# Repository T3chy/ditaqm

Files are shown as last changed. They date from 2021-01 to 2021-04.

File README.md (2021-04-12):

# Do-it-Together Air Quality Measuring!

## Welcome!
Below are the links to all of the documents you need to get your very own distributed air quality sensor mesh set up!

# Paper Abstract
[Check it out!](ABSTRACT.pdf)

## Sensor Setup
- [ESP32](docs/esp32/) (the cool one)

- [Raspberry Pi](docs/raspi/)

## Web server / Database Setup

- [Spin up a dashboard for your data with POST endpoints for data collection!](docs/server.md)

- [Configure and host MySql database to store your data!](docs/db.md)

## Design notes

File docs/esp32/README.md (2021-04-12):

# Embedded, low cost, ESP32 Air Quality Cluster
## What more could you ask for?

## Note

This is currently in development, but you can

-[Read the abstract!](../../ABSTRACT.pdf)

-Check out the [pcb](../../boards/esp32/hardware/pcb/) and [enclosure](../../boards/esp32/hardware) designs!

-Take a look at the [firmware source code!](../../boards/esp32/firmware)

## Welcome!
Below are the steps to set up your very own ESP32-based DITAQM sensor cluster board!

To get a cluster board up and running, you have two options:

[Purchase a Pre-Built board (and support a high school air quality club!)](#pre-built)

[Build it from scratch (don't worry! It's not as hard as it might sound :))](#from-scratch)

## From Scratch!

### Step 1: Ordering the Components and PCBs
I have used [LCSC](https://lcsc.com) for the components and [JLCPCB](https://jlcpcb.com) for the PCBs during development, but there is nothing in the source files that will only work with those distributors. If you want the easiest possible experience, use either Mouser or LCSC for your components, because I have included distributor-specific part numbers for them in the BOM. Ok, let's get ordering!

#### Ordering the components
This will be a guide for ordering the components on LCSC, it is probably similar on any other major components distributor with a BOM tool.

1. Head over to [lcsc](https://lcsc.com) and click on BOM Tool

2. Download the [BOM](../../boards/esp32/hardware/pcb/bom.csv) and upload it to the site

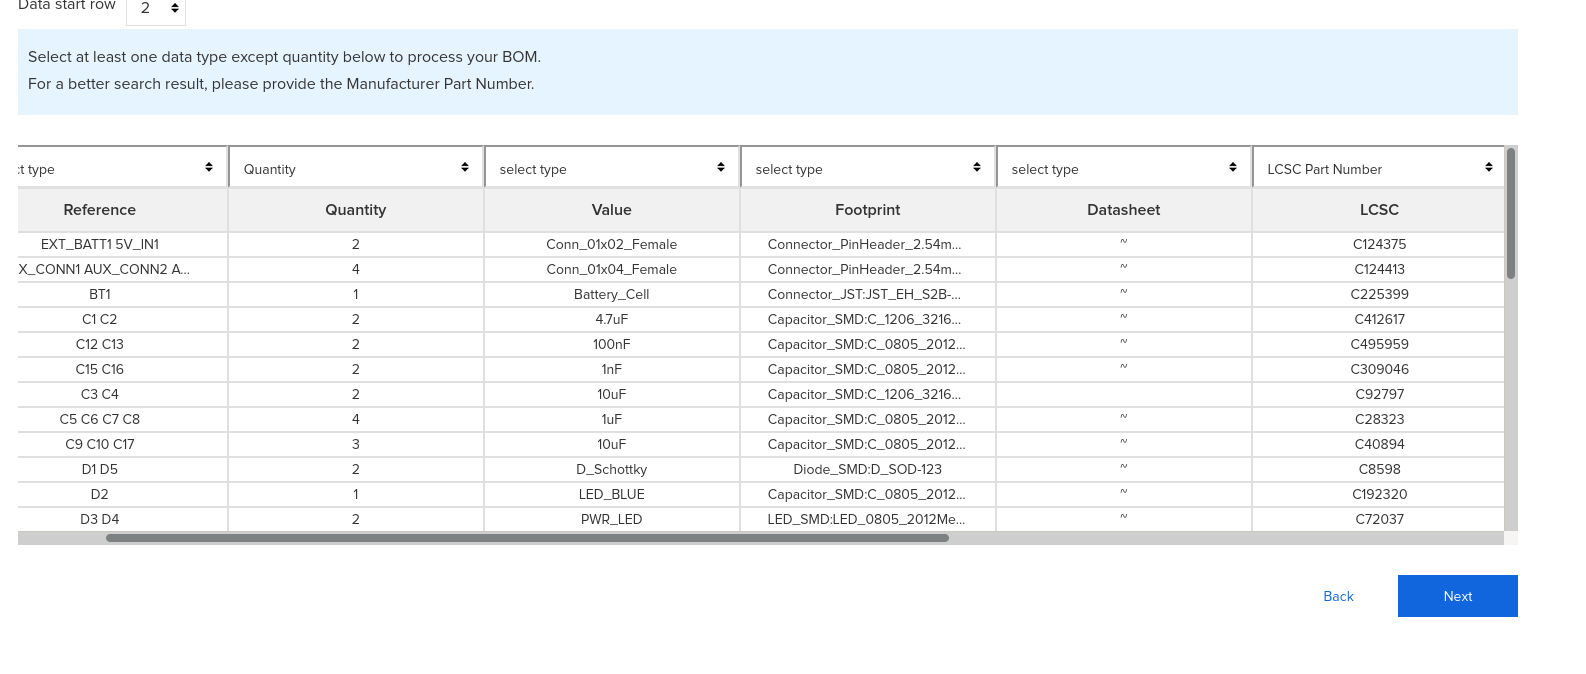
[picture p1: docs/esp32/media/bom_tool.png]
bom tool Finalizing the BOM
3. Once you upload the BOM, you should see a spreadsheet appear. All you need to do is set the "quantity" column to "Quantity" and the "LCSC" column to "LCSC Part Number", as seen in the picture below  

5. Click next, and you will be shown a list of the items required for one unit. Keep in mind that many of the passive components (resistors, capacitors) require a minimum order quanity of between 20 and 100 units, but they cost fractions of cents so don't worry too much about it. Also consider that the BME680 and PMS7003 sensors are included in the LCSC bom, and are by far the most significiant contributors to price. If you laready have these sensors, take them off the list with the trashcan button and that should take your price down quite a bit. Next to the "Add to cart" button there is a multiplier, use that if you are ordering parts for multiple sensor clusters. Keep in mind that if you put, say, 100 qty for a component and multiply that by 4 orders, you will have 400 units in your cart, which is way over the order quantity. Keep that in mind when selecting component qunatities.

7. Once you're ready, you can add the components to cart and check out!

#### Ordering the PCBs
1. Head over to [JLCPCB](https://jlcpcb.com) and click on the big blue "QUOTE NOW" button

2. Download the [PCB Design Files](../../boards/esp32/hardware/pcb/src.zip), click "Add gerber file" and upload the src.zip you just downloaded.

3. Leave all options as default, this will ensure the fastest manfucaturing time and lowest cost

4. Save to cart and checkout!

**Note that JLCPCB will usually take around a week to arrive (with DHL shipping) while LCSC may take up to 2 and a half, depending on which shipping you chose and how long it takes to gather your components in the warehouse**

### Step 2: Assembling
I'll probably make a video on this just open the kicad and follow that or I'll make a key for component designators or smth

**IMPORTANT if you aren't getting any power from the Micro-USB/5V source, check to see if you installed diode D1 backwards! This has happened a few times to me and I only realized that it was the problem when the diode started heating up and I wasn't getting any voltage through the LDO regulator while powered off of the battery.

### Step 3: Flashing the Firmware
If you want, you can use an [esp32-wroom flashing device]() to flash the ESP32 before you solder it in. If you choose to assemble the cluster fully before flashing the firmware, follow the instructions below.

1. Download [esptool]((). This is the standard software package used to flash firmware to Espressif devices, including the ESP32 we are using.
2. Since there is no onboard usb-serial IC on the board, you will need to use an external one. Once you have that device plugged in, wire the external device's RX to your cluster's TX and the device's TX to your cluster's RX. You will also need to connect the ground header on the flashing device to any ground (either marked GND or -, it doesn't matter which one you use) in order to allow voltage to flow. Once you have wired everything up, power the cluster through either a micro usb power supply or a battery, holding the IO0 button before, during, and a few seconds after powering the device. This puts it in 'firmware upload mode' and is the mode we need to be in to flash firmware.

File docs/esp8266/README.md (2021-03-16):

probably just use the esp guide and wire the sensors with jumpers the micropython should be fine

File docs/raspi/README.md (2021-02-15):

# DIYAQI Sensor Deployment Protocol: Raspberry Pi

## Welcome!

Below are the steps to set up your very own Raspberry-Pi based air quality monitoring station

## Table of Contents

**[Components list](#components)**

**[Burning an OS Image](#burning-a-raspberry-pi-os-image)**

**[Pre-Boot Configureatiuon](#headless-config)**

**[First Boot!](#first-boot)**

**[SSHing in](#sshing-in)**

**[Next Steps](#once-youre-in)**

#### Note: If you already have a set up Pi, skip to **[Next Steps](#once-youre-in)**, starting in the home directory

## Components

 Make sure you have all of your components; This includes

	- Raspberry pi Zero W*
	- BME280 Sensor with headers
	- 4 female to female jumper wires
	- a micro USB cable to power your pi
	- a micro SD card (at least 16GB in size)
	- Some way to interface with your microsd card (adapter, port, etc)
	- A computer running Windows, OS X (macOS), or linux**

**Note: you will need to wire up to the GPIO pins on the pi, so gettting a version with presoldered headers is recommended if you don't want to solder them yourself**

*no reason other versions shouldn't work if they have wifi (or are connected to ethernet), but untested

**if you use BSD you probably don't need to be reading this, but welcome! use dd or something lol

## Burning a Raspberry Pi OS Image

Let's get to work! There are two options to burn Raspberry Pi OS onto your pi.

#### Option 1: Raspberry Pi Imager (Recommended)

1. Download the latest version of Raspberry Pi Imager setup from https://www.raspberrypi.org/software/
2. Launch the setup and install it following the instructions shown on screen
3. Plug in your MicroSD card
4. Launch Raspberry Pi Imager
5. Click on `CHOOSE OS` -> `Raspberry Pi OS (other)` -> `Raspberry Pi OS Lite (32-bit)`
	- Note! This tutorial only requires the "Lite" verison, but feel free to download either the "with desktop" or "with desktop and recommended software" versions if you perfer, those will work too!
6. Click on `CHOOSE SD CARD` and select your MicroSD card from the list
7. Click `WRITE` and `YES`, and when it finishes click `CONTINUE` and close the program. Now you should have a bootable version of Raspberry Pi OS! Just a few more things to do before we put that card in the Pi

#### Option 2: Manual (Download Image + BalenaEtcher)

1. Download the latest Raspberry Pi OS (formerly Raspian) image from https://www.raspberrypi.org/software/operating-systems/
	- Note! This tutorial only requires the "Lite" verison, but feel free to download either the "with desktop" or "with desktop and recommended software" versions if you perfer, those will work too!
2. Unzip the image. This can usually be done by right clicking the .zip file and clicking "extract here" or something similar
3. Download and install BalenaEtcher from https://www.balena.io/etcher/ for whatever operating system you are on
4. Plug in your MicroSD card
**Warning: the next steps will wipe all current data on your MicroSD Card**
5. Open BalenaEtcher (you may need to open it with admin privileges)
	- Click "Flash from file" and select the .img you extracted in step 3
	- Click "Select target" and then select your MicroSD card (make sure you aren't accidentally burning the image to a random flash drive that's plugged in!)
	- Click "Flash!" and wait for Etcher to do its thing (flashing and verifying your flash)
6. Once BalenaEtcher finishes, you should have a bootable version of Raspberry Pi OS! Just a few more things to do before we put that card in the Pi

## Headless Config

We will be setting up the pi "headless", which means we won't need to connect anything to it besides power to use it

This requires us to do some manual setup on the pi before we boot it up for the first time, but don't worry! Just follow the instructions carefully and you should be good to go!

Firstly, we need to enable ssh (secure shell) on the pi
	 (secure shell is a method by which a computer can remotley access another computer)

### Enabling secure shell access (ssh)
When you burned your Raspberry pi OS image, there should have been two 'partitions' created on your SD card. They will appear, on most operating systems, as two individual devices. We need to access the "boot" partition, which is the first partition and is also the smaller one. If you cannot find either, the imager may have automatically ejected the MicroSD card. In that case, just remove it and reinsert it.

**Look for files named "start.elf" and "cmdline.txt" to confirm you are in the boot partition**

Once you get into the boot partition, make a file called "ssh" with no extension and save it. An easy way of doing that on Windows is to make a text file but remove the `.txt` extension. Make sure that the system recognizes it as just a "file" and not a text document. The text inside it doesn't matter, so you can put anything you want in there (or nothing, it doesn't matter)

**SSH will now be enabled on first boot!**

### Automatically connecting to WiFi

**Note: skip this section if you are using ethernet (wired internet) for internet connectivity**

To automatically connect to wifi, we need to change a file called "wpa_supplicant.conf"; This file manages your Raspberry Pi automatically connecting to wifi on boot

Luckily, all we need to do is put our wpa supplicant in the boot folder and Rasberry Pi OS will locate it correctly for us! Isn't that nice? Let's do that real quick.

1. Create a file in the same boot folder we just put that 'ssh' file in, call it "wpa_supplicant.conf"
2. In that file put the following text, replacing <SSID> with your wifi network name, and <PASS> with that network's password (keeping the quotes around them)
	- If you live outside of the US, swap "US" for whatever ISO 2 letter code your country has

```
ctrl_interface=DIR=/var/run/wpa_supplicant GROUP=netdev
update_config=1
country=US

network={
 ssid="<SSID>"
 psk="<PASS>"
}
```

**Your device is now ready for its first boot!**

## First boot!

The pi will take a little while to get itself going, go grab a coffee and give around 10 minutes to initalize.

Once you've given your pi 10 minutes to set up, we can access it from our computer!

## SSHing in

For MacOS or linux, you will aready have ssh installed. For windows, you MAY have ssh installed; try the steps below, and if you get an "ssh is not recognized as an internal or external command" kind of thing, follow the instructions for "ssh (PuTTY)" below

### MacOS, Linux, and (Modern) Windows

open your terminal and type in the following command and press enter

```shell
ssh pi@raspberrypi
```

You should be greeted with

```
pi@raspberrypi's password:
```

The default password is "raspberry" (when you type, nothing will show up. This is normal! Just type "raspberry" and press enter)

**Note: you may see something that looks like**
```
The authenticity of host 'raspberrypi (192.168.3.127)' can't be established.
ECDSA key fingerprint is SHA256:/ZBKVpFcCJh4Fl1gzgwIviCVNRWDBXFxL+WTL4TO+Fw.
Are you sure you want to continue connecting (yes/no/[fingerprint])?
```
**before you are prompted for the password, just type "yes" and press enter to continue**

### Legacy Windows (PuTTY)

install [PuTTY](https://www.chiark.greenend.org.uk/~sgtatham/putty/latest.html), a simple ssh client for windows

1. open PuTTY

2. enter "raspberrypi" as the hostname, leave the port at 22 and press "Open"
3. enter "pi" to "Login As:"
4. Enter "raspberry" to "pi@raspberrypi's password:"

## Once you're in
Once you enter the password and press enter, a few lines looking similar to those below will appear (if you got the password right)

```
Linux raspberrypi 4.19.118-v7l+ #1311 SMP Mon Apr 27 14:26:42 BST 2020 armv7l
The programs included with the Debian GNU/Linux system are free software;
the exact distribution terms for each program are described in the
individual files in /usr/share/doc/*/copyright.
Debian GNU/Linux comes with ABSOLUTELY NO WARRANTY, to the extent
permitted by applicable law.
Last login: Fri Jun 26 10:21:38 2020 from 192.168.43.138
pi@raspberrypi:~ $
```

The version number and time will be different, but the important part is that you get that `pi@raspberrypi:~$`. That means you're in (you have a shell, or command line access on/to the pi)!

(*If you want, you can change the default password of "raspberry" by typing "passwd" in the shell prompt, pressing enter, and following the password change prompts*)

We now need to set up the sensor, and get it reporting. You're doing great!

We now need to set up the sensor, configure where we're sending the data, and configure the data-sending script to start every time we turn on our pi. Sounds like a lot, doesn't it? Luckily, most of the process is automated (thanks, scripting!).

All you need to do is run the following command while you're at the `pi@raspberrypi:~ $` prompt

```
wget https://raw.githubusercontent.com/T3chy/diyaqi/main/boards/raspi/setup.sh && sudo chmod +x setup.sh && sudo ./setup.sh
```

**You will be prompted for your password after running this command; simple enter 'raspberry' (without the quotes) or the new password you previosly set and press enter.**

Follow the prompts in the script, and you should be good to go! Congratulations!!

## Troubleshooting

#### "I see \"The package cache file is corrupted\" !! Help!!
**Solution: run**

```
sudo rm -rf /var/lib/apt/lists/*
```

entering your password as needed, and then re run the install script with

```
sudo ./setup.sh
```

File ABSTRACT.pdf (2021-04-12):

# DITAQM- an Educational Framework for a Embedded, Low-Cost, and Open-Source Air Quality Sensor Package

Elam Day-Friedland
Albany High School, Albany, California, USA

April 12, 2021

## Abstract

In this paper, we present a fully integrated framework for distributed air quality sampling with a focus on STEM education and extensions to add more sensors. This is aimed at high-school students with an initial exposure to computer programming. (we expect that teachers / student will do this collaborativley) Within this framework we have included a custom-designed embedded circuit integrating four discrete air quality sensors run by an ESP32 (a WiFi enabled microcontroller). The four natively supported sensors were chosen with consideration for the ability to detect a breadth of pollutants as well as cost and are as follows: the PMS7003 particulate matter sensor, the MiCS6814 MultiGas sensor, the BME280/680 temperature, pressure, humidity, and organic compound (BME680 only) sensor, and the MH-Z19B CO2 NDIR CO2 sensor. The firmware is written in MicroPython, a subset of the Python 3.4 standard optimized for low-spec devices such as microcontrollers, so that it is simple to set up, with no data wires required after initial flashing yet easy to extend. The cluster is contained within a 3D printed enclosure designed to withstand both indoor and harsh outdoor environments. The framework uses a docker-based NodeJS and MySQL stack for handling and coordinating users, sensors, and data. All source files referenced in this paper are available at https://github.com/t3chy/diyaqi. We designed this project to be fully free and open source, with the software and hardware components licensed under the GNU General Public License v3 and CERN Open Hardware License v2 (Strongly Reciprocal) respectively.
© 2021 Elam Day-Friedland

1

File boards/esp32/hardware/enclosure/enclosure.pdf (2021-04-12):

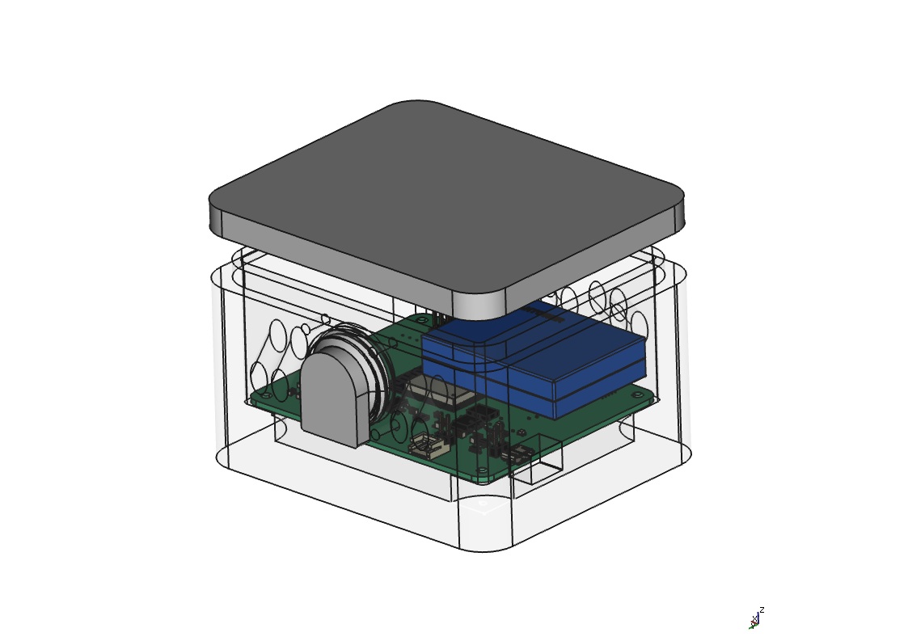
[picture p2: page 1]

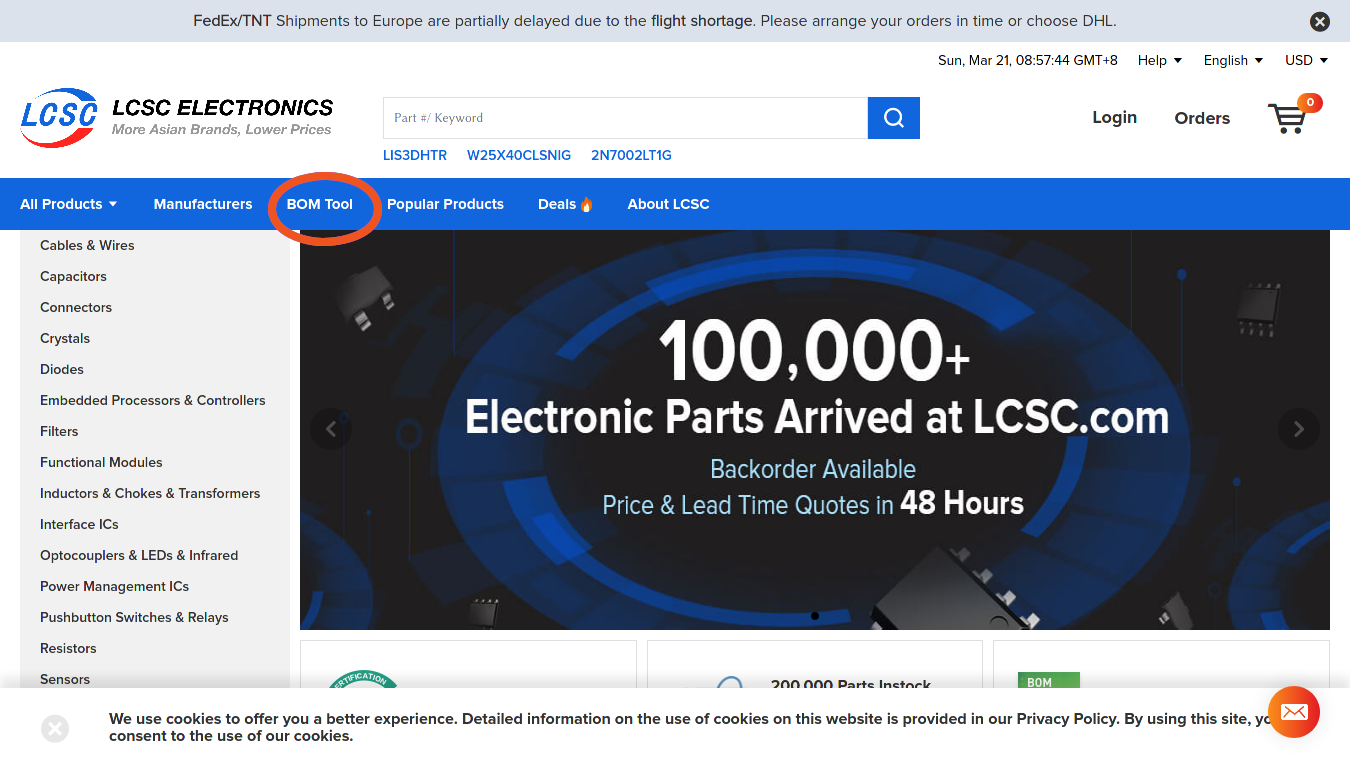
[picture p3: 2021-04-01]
docs/esp32/media/lcsc_home.png

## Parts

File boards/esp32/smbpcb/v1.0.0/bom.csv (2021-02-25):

Reference | Quantity | Value | Footprint | Datasheet | LCSC | mfr_part_num | Mouser
EXT_BATT1 5V_IN1 | 2 | Conn_01x02_Female | Connector_PinHeader_2.54mm:PinHeader_1x02_P2.54mm_Vertical | ~ | C124375 | C124375
AUX_CONN1 AUX_CONN2 AUX_CONN3 AUX_CONN4 | 4 | Conn_01x04_Female | Connector_PinHeader_2.54mm:PinHeader_1x04_P2.54mm_Vertical | ~ | C124413 | C124413
BT1 | 1 | Battery_Cell | Connector_JST:JST_EH_S2B-EH_1x02_P2.50mm_Horizontal | ~ | C225399 | A2501WR-2P
C1 C2 | 2 | 4.7uF | Capacitor_SMD:C_1206_3216Metric | ~ | C412617 |  | 963-UMJ316BC7475KLHT
C12 C13 | 2 | 100nF | Capacitor_SMD:C_0805_2012Metric | ~ | C495959 |  | C0805X104K101TB
C15 C16 | 2 | 1nF | Capacitor_SMD:C_0805_2012Metric | ~ | C309046 |  | TCC0805X7R102K501DTS
C3 C4 | 2 | 10uF | Capacitor_SMD:C_1206_3216Metric | ~ | C412617 |  | 963-UMJ316BC7475KLHT
C5 C6 C7 C8 | 4 | 1uF | Capacitor_SMD:C_0805_2012Metric | ~ | C28323 |  | 187-CL21B105KBFNNNE
C9 C10 C17 | 3 | 10uF | Capacitor_SMD:C_0805_2012Metric | ~ | C40894 |  | 0805X106K250NT
D1 D5 | 2 | D_Schottky | Diode_SMD:D_SOD-123 | ~ | C8598 |  | 833-B5819W-TP
D3 D4 | 2 | PWR_LED | LED_SMD:LED_0805_2012Metric | ~ | C72037 |  | 755-SML-H12U8TT86C
J1 | 1 | USB_B_Micro | Connector_USB:USB_Micro-B_Molex-105017-0001 | ~ | C404969 | MicroXNJ
J2 | 1 | PMS7003 | mics:PMS7003 | https://www.espruino.com/datasheets/PMS7003.pdf | C84815 | PMS7003
L1 | 1 | 4.7uH | Capacitor_SMD:C_0805_2012Metric | ~ | C479902 |  | SCMI201209U4R7KT
Q1 | 1 | SUD08P06-155L | Package_TO_SOT_SMD:TO-252-2 | https://www.vishay.com/docs/62843/sud08p06-155l-ge3.pdf | C558294 |  | 781-SUD08P06-155L-E3
Q2 Q3 | 2 | SS8050_NPN | mics:sot-23-3 |  | C2150 |  | 750-SS8050-G
R1 R15 R25 | 3 | 2k | Capacitor_SMD:C_0805_2012Metric | ~ | C328391 |  | AECR0805F2K00K9
R10 | 1 | 820 | Capacitor_SMD:C_0805_2012Metric | ~ | C352174 |  | AECR0805F820RK9
R11 R12 R13 R14 R16 | 5 | 1k | Capacitor_SMD:C_0805_2012Metric | ~ | C416075 |  | CR-05FL7----1K
R17 R18 | 2 | 4.7k | Capacitor_SMD:C_0805_2012Metric | ~ | C269733 |  | RMC08054.7K5%N
R19 | 1 | 27 | Capacitor_SMD:C_0805_2012Metric | ~ | C104178 |  | RTT0527R0FTP
R2 R3 R4 R5 R22 R23 | 6 | 10k | Capacitor_SMD:C_0805_2012Metric | ~ | C269724 |  | 71-TNPU080510K0AWEN
R20 | 1 | 130 | Capacitor_SMD:C_0805_2012Metric | ~ | C17451 |  | CR0805-FX-1300ELF
R24 R26 R28 | 3 | 470 | Capacitor_SMD:C_0805_2012Metric | ~ | C136570
R27 | 1 | 5.1k | Capacitor_SMD:C_0805_2012Metric | ~ | C328405 |  | 71-CRCW06035K10FKEAC
R6 | 1 | 330k | Capacitor_SMD:C_0805_2012Metric | ~ | C328392 |  | AECR0805F330KK9
SW1 SW2 | 2 | RESET | Button_Switch_SMD:SW_SPST_Omron_B3FS-101xP | ~ | C589246 | ST-1102W-4.3
U1 | 1 | MCP73831-2-OT | Package_TO_SOT_SMD:SOT-23-5 | http://ww1.microchip.com/downloads/en/DeviceDoc/20001984g.pdf | C424093 |  | 579-MCP73831T-2ACIOT
U2 | 1 | SGM6603-5.0YN6G_TR | Package_TO_SOT_SMD:SOT-23-6 | https://www.analog.com/media/en/technical-documentation/data-sheets/4440fb.pdf | C79689 |  | SGM6603-5.0YN6G/TR
U3 | 1 | ESP32-WROOM-32 | RF_Module:ESP32-WROOM-32 | https://www.espressif.com/sites/default/files/documentation/esp32-wroom-32_datasheet_en.pdf | C82899 |  | 356-ESPWROOM3216MB
U4 | 1 | SSD1306 | mics:SSD1306_OLED-0.91-128x32 | https://datasheet.lcsc.com/szlcsc/1809291515_Shenzhen-Allvision-Tech-QG-2832TLBFG02_C91220.pdf | C91220 | QG-2832TLBFG02
U5 | 1 | BME680 | Package_LGA:Bosch_LGA-8_3x3mm_P0.8mm_ClockwisePinNumbering | https://ae-bst.resource.bosch.com/media/_tech/media/datasheets/BST-BME680-DS001.pdf | C125972 | BME680 | 262-BME680
U7 | 1 | AMS1117-3.3 | Package_TO_SOT_SMD:SOT-223-3_TabPin2 | http://www.advanced-monolithic.com/pdf/ds1117.pdf | C369933 | AMS1117-3.3 | 595-REG1117-3.3/2K5

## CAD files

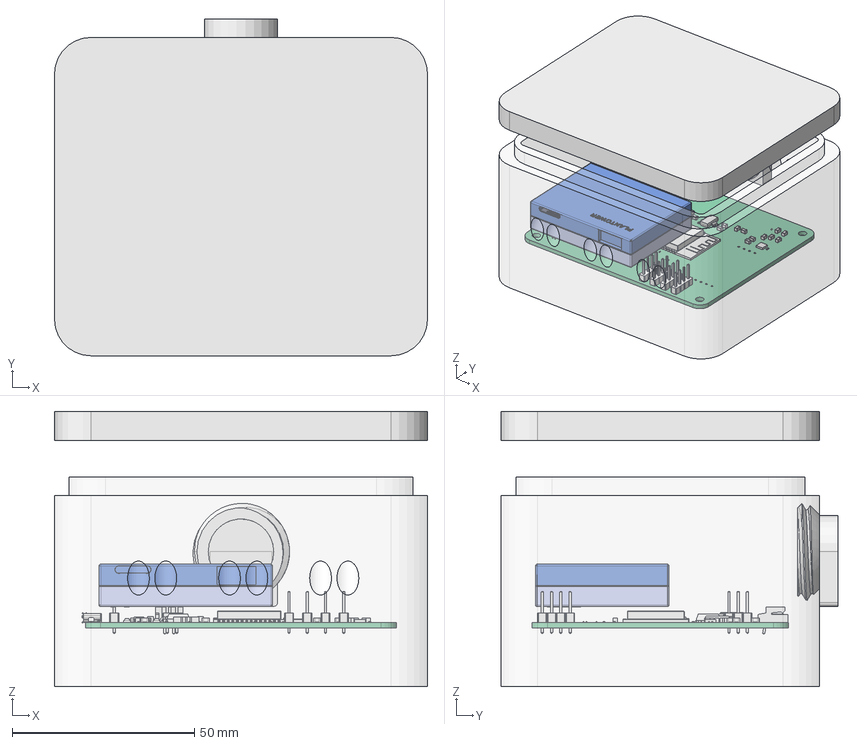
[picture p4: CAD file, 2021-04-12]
boards/esp32/hardware/enclosure/enclosure.FCStd
102.4 x 92.4 x 75.5 mm
Pcb_cdf5
"D5"_D_SOD_123_1408c4fc-6b3f-41e9-9cd8-0f3e23f1e909 x 2
"R28"_C_0201_0603Metric_1e49d41b-6dbe-4e9f-8123-0b88ccebfb2b x 22
"U7"_SOT_223_277a91eb-0315-4cbd-868e-a1e975d6badf
"U1"_SOT_23_5_29c8d3b7-63d8-49c3-b167-1e640a277db6
"EXT_BATT1"_PinHeader_1x02_P254mm_Vertical_2caa2f45-1abb-4877-a58f-1c21ac1dffa2 x 2
"C3"_C_1206_3216Metric_2dba1fc2-255c-43e1-b902-5e91cda70795 x 3
"R8"_C_0805_2012Metric_2f24beb7-e3a1-4d04-bd95-c3c9f92215c0 x 18
"AUX_CONN2"_PinHeader_1x04_P254mm_Vertical_2f8dc1ef-574c-48e6-a60d-e7c7da9fe127 x 4
"Q1"_TO_252_2_30f5009c-511e-4eab-8ab9-cd5aa0241904
"U5"_Bosch_LGA_8_3x3mm_P08mm_ClockwisePinNumbering_4cf723d9-7f93-4c14-b486-45e603f1d024
"U2"_Texas_S_PVSON_N10_62902abe-9812-46b5-a42c-a6af39063f47
"J1"_USB_Micro-B_Molex_47346-0001_7afd3e19-8ad3-4394-a5f0-daa53f96cca8
"BT1"_JST_S2B_EH_a59a4e64-c94d-4edc-84de-77e5b6c3af01
"D3"_LED_0805_2012Metric_aaae8f97-22a9-41f0-8481-7001413f332c x 2
"IC1"_Open CASCADE STEP translator 6.8 1_e548121f-f310-44b3-90db-60773fd45095
"U3"_ESP32-WROOM-32_fbe577f8-ea7d-4210-bfb3-b57f67bc03ec
lid
rain_cover

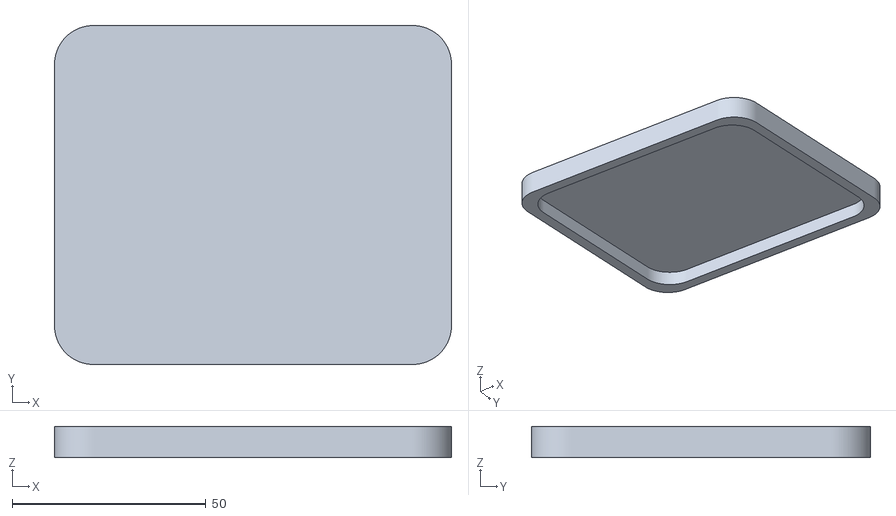
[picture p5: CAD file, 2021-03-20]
boards/esp32/hardware/enclosure/enclosure-lid.stl
102.4 x 87.4 x 8.00

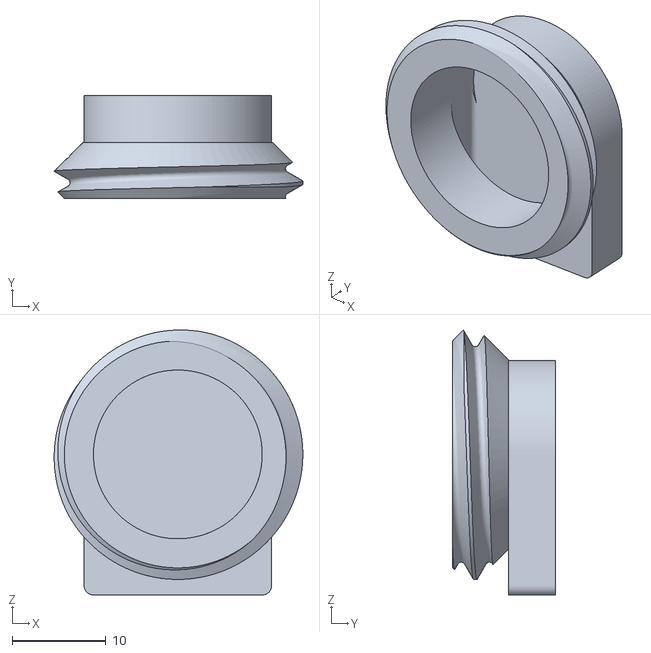
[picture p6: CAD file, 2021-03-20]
boards/esp32/hardware/enclosure/enclosure-rain_cover.stl
26.5 x 11.0 x 28.3

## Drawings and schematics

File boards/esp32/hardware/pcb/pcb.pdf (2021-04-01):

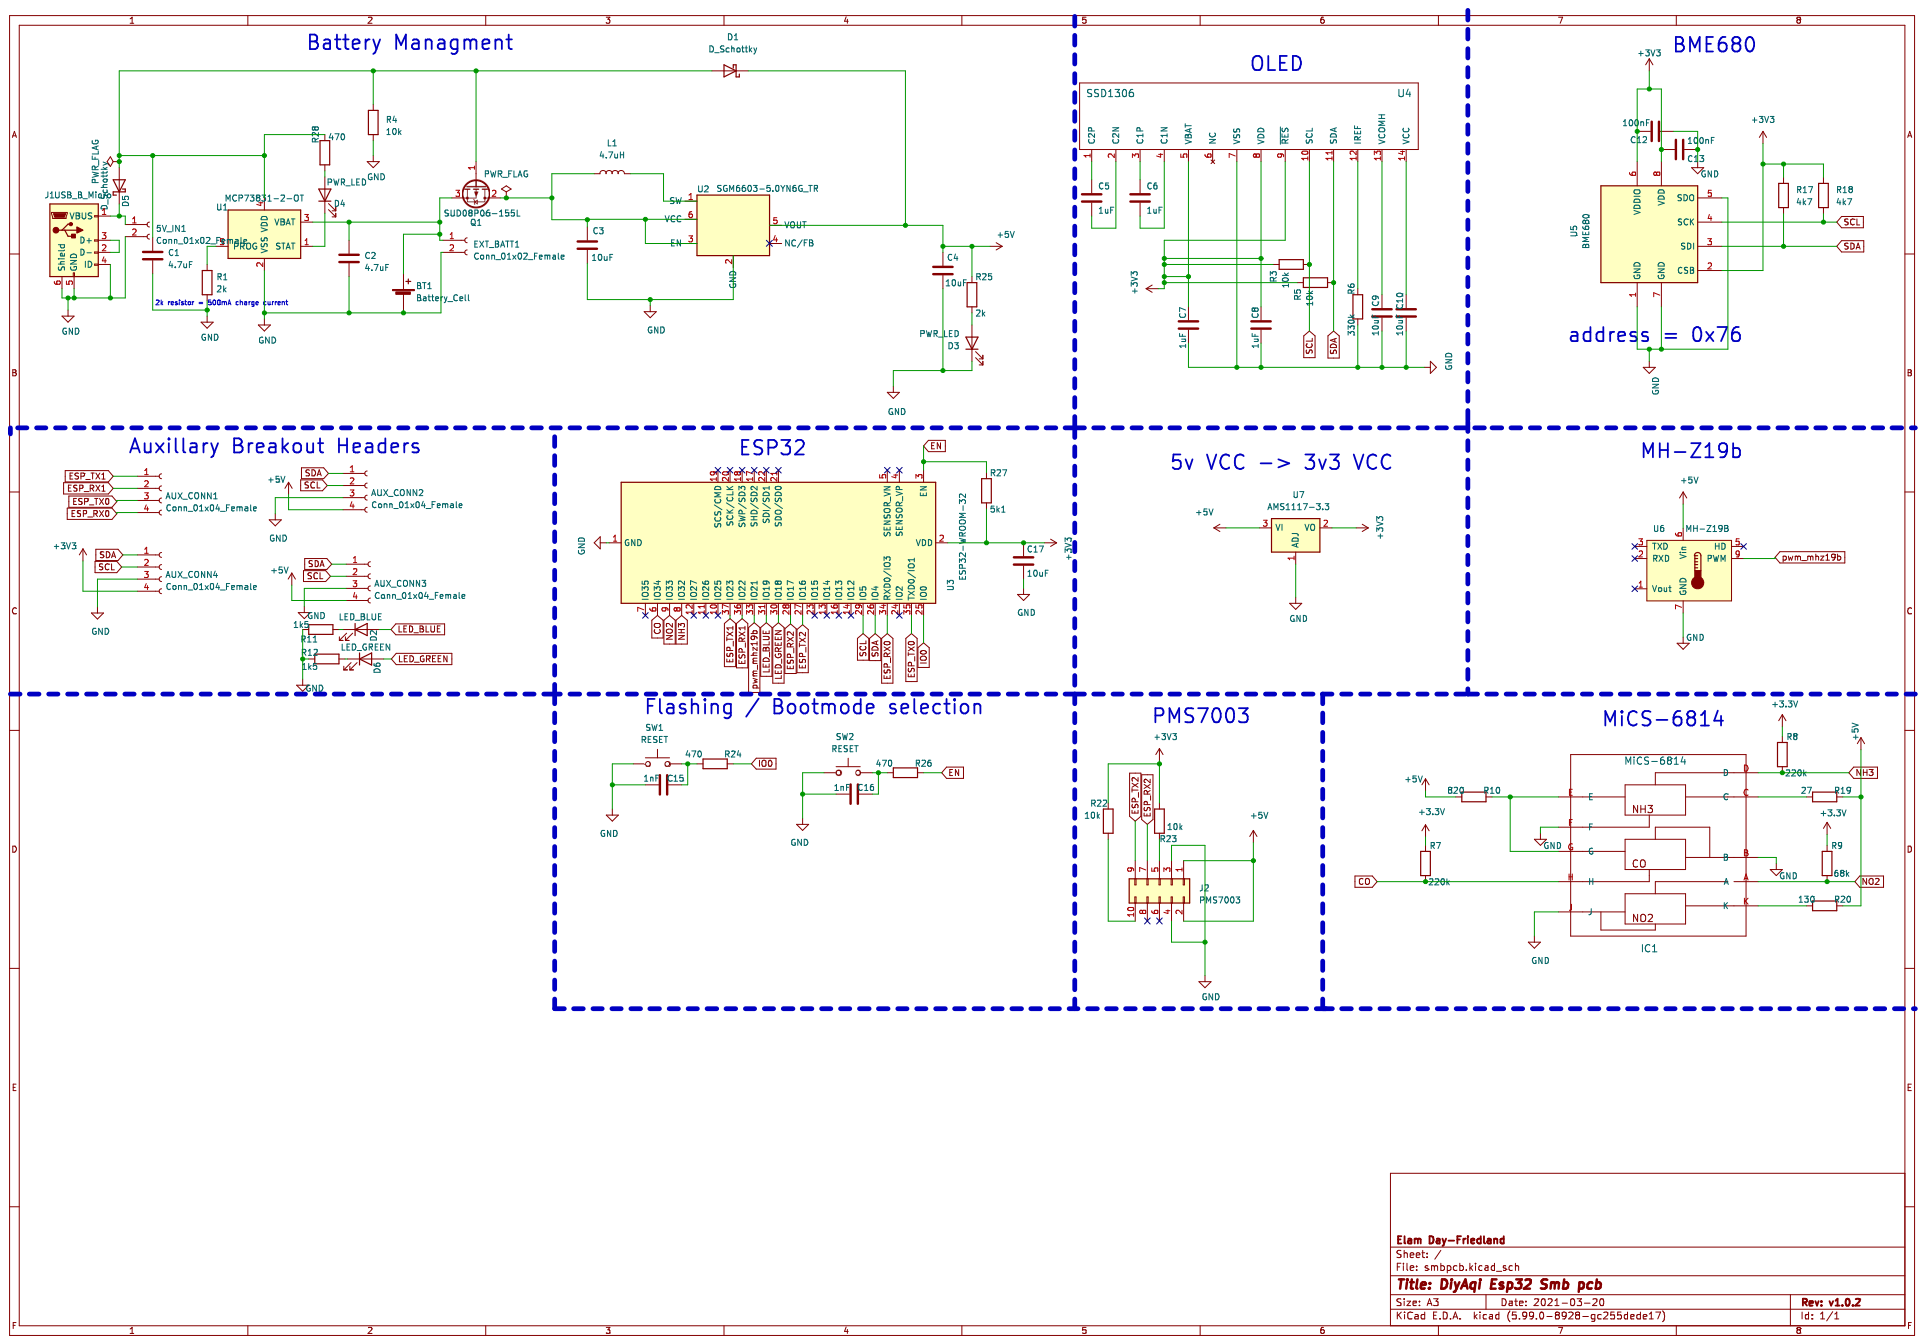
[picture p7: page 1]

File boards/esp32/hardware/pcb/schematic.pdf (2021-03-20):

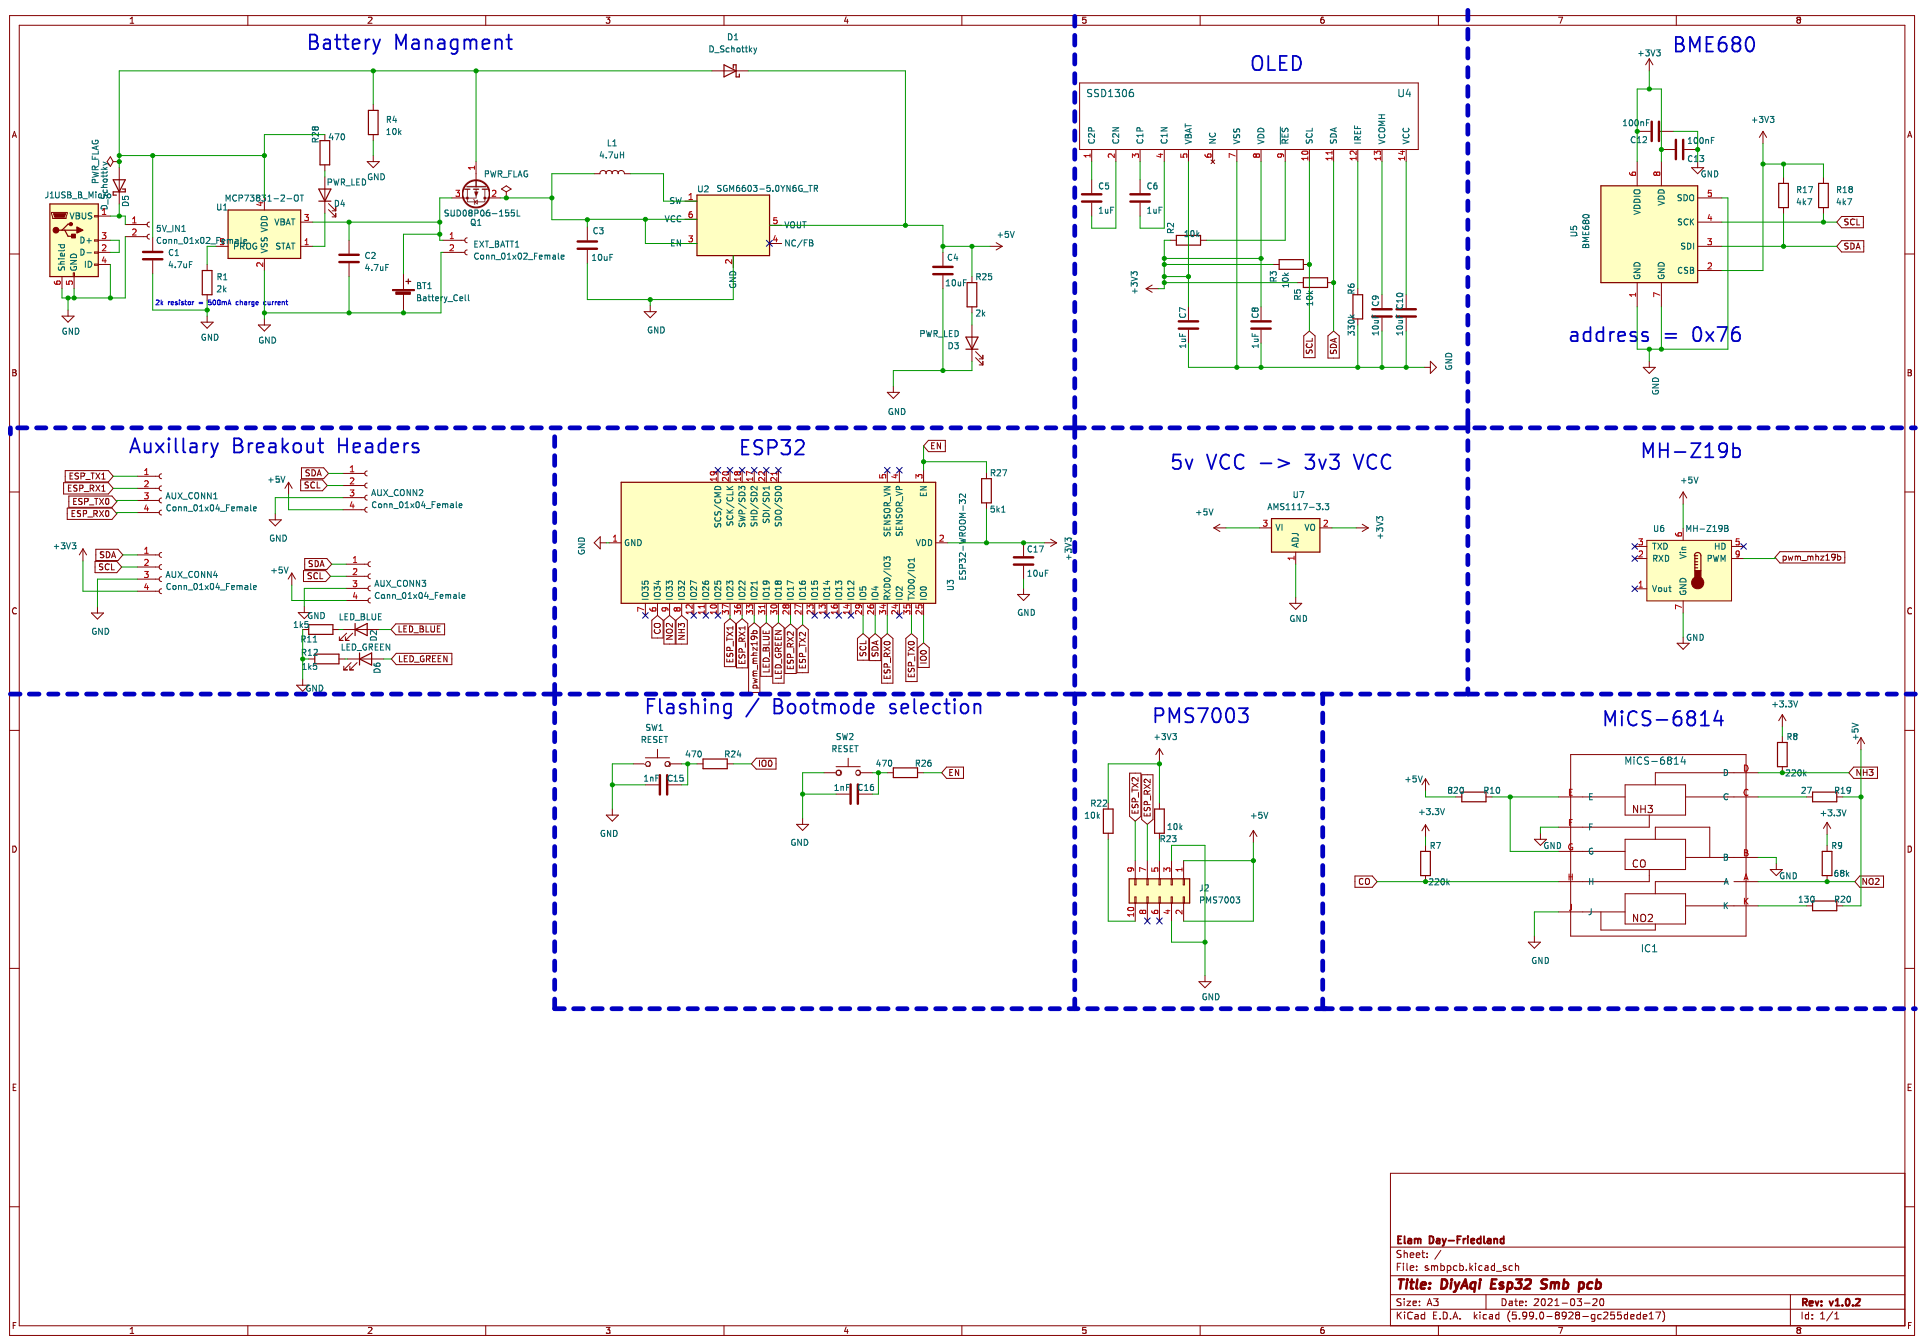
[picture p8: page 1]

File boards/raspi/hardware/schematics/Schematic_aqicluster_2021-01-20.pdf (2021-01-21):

## MH-Z19

CO2

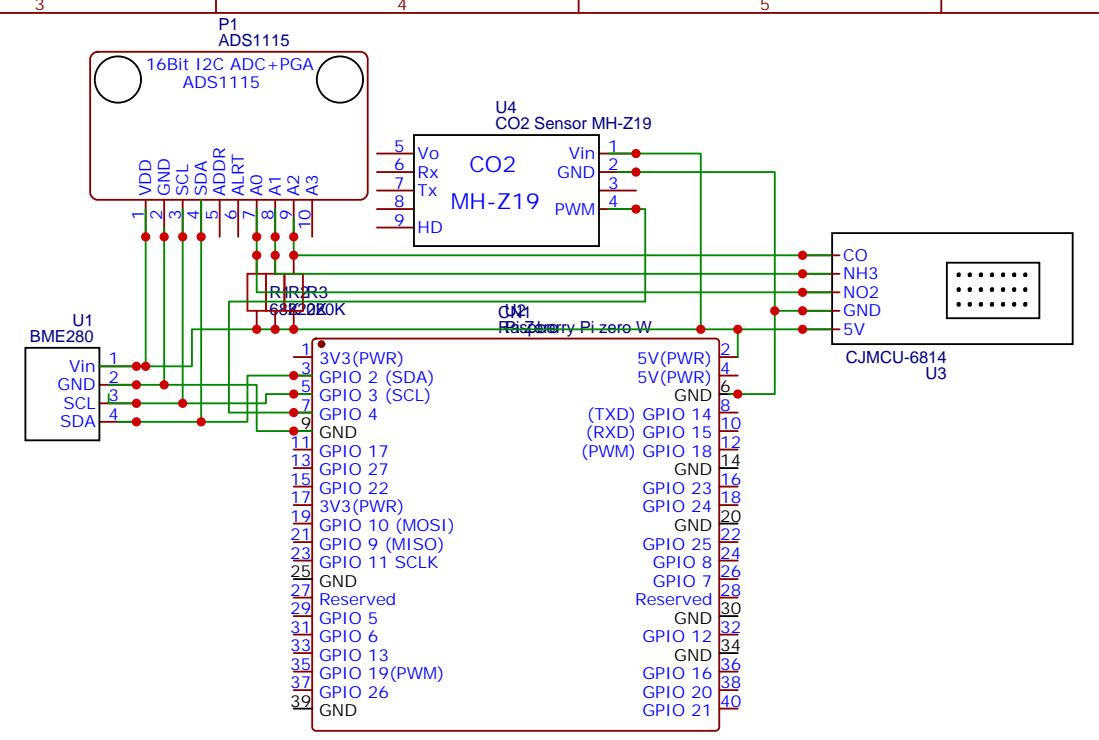
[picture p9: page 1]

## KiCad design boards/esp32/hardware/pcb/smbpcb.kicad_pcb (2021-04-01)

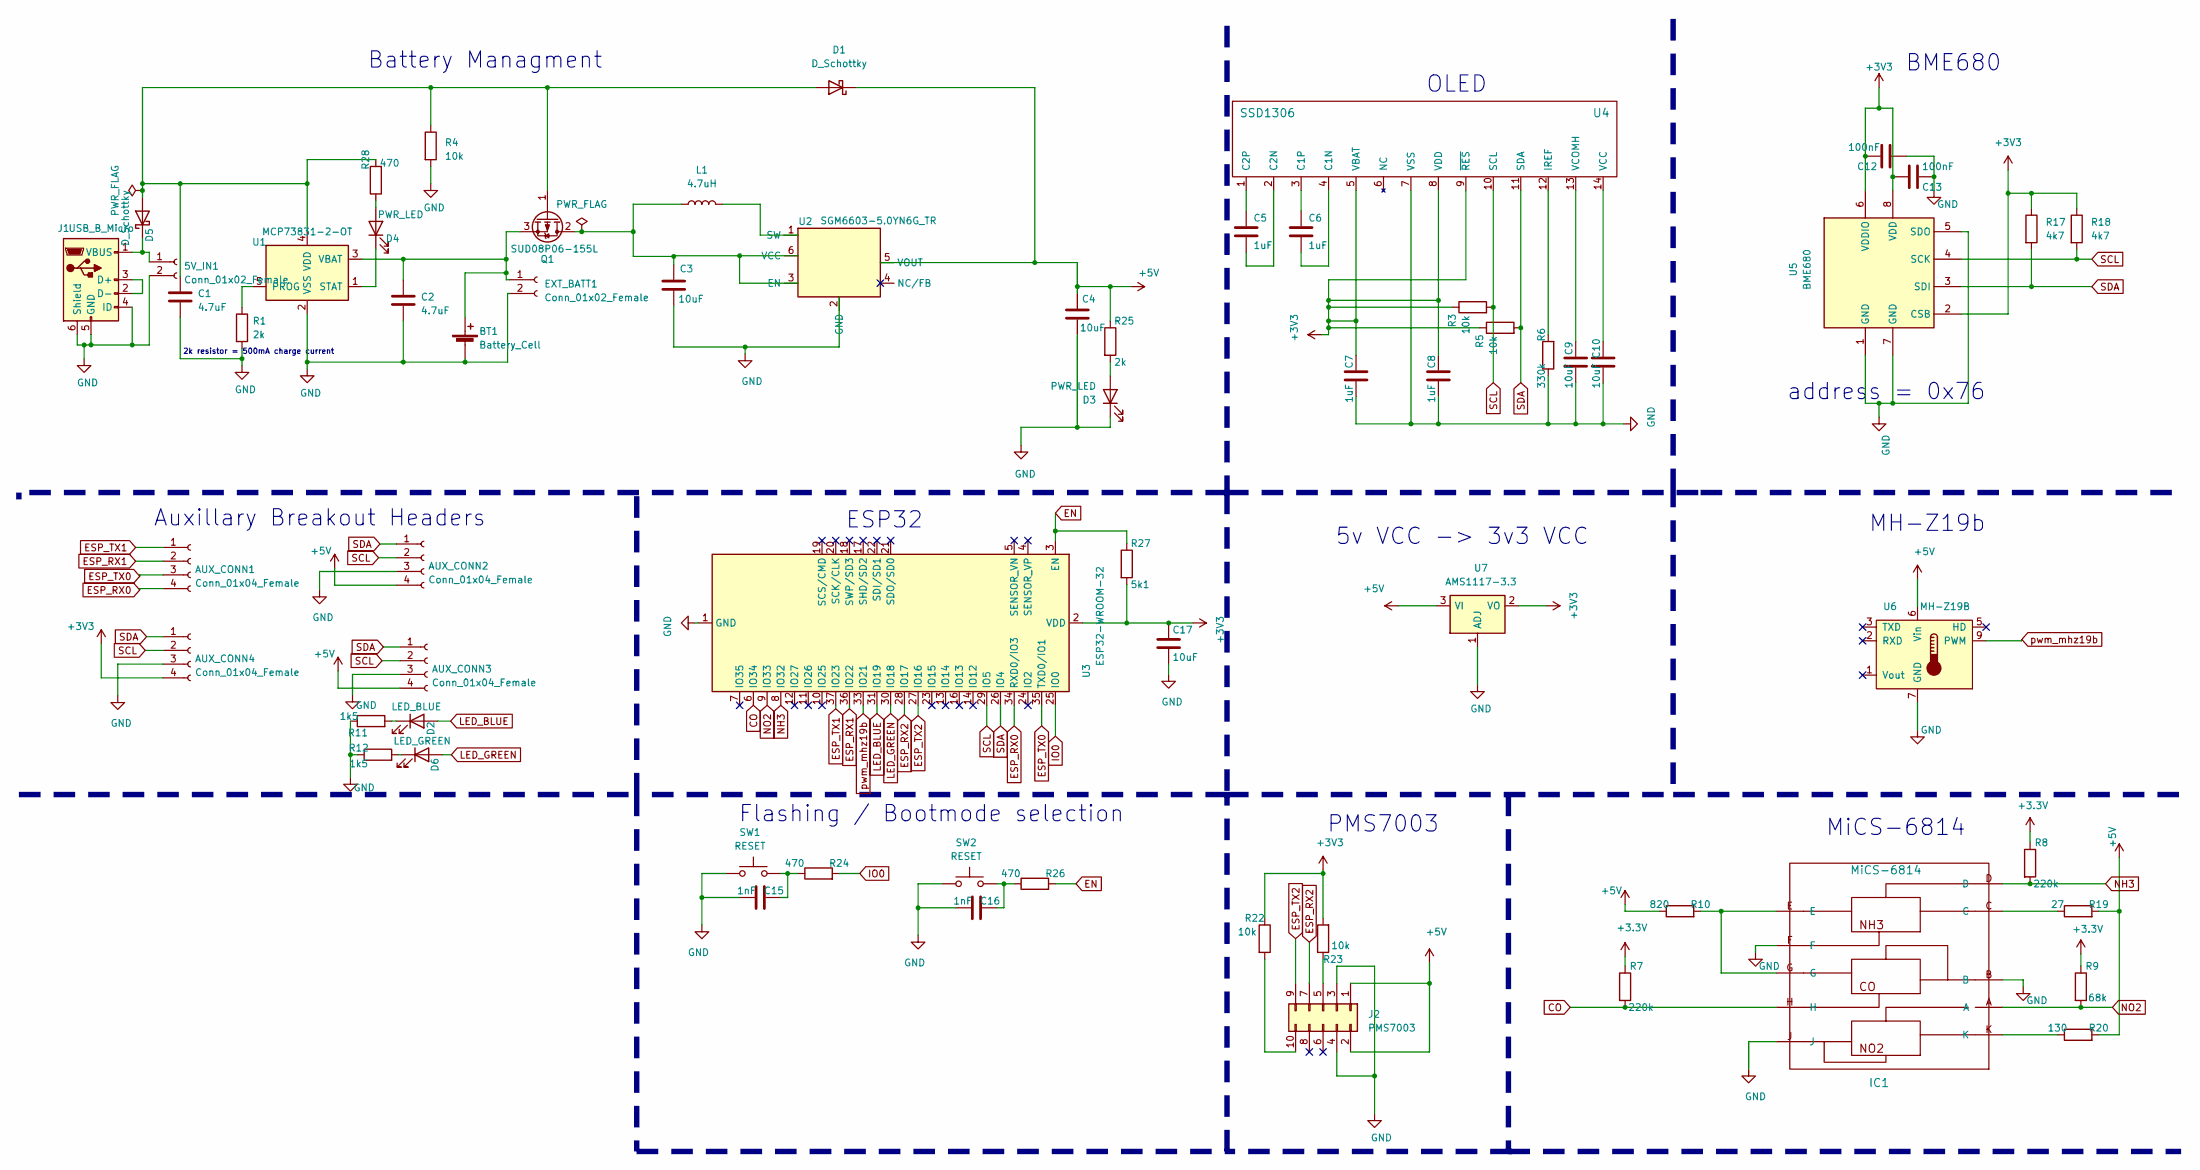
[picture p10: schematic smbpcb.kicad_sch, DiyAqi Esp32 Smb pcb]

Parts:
5V_IN1: Conn_01x02_Female; PinHeader_1x02_P2.54mm_Vertical; mfr_part_num C124375; LCSC C124375
AUX_CONN1, AUX_CONN2, AUX_CONN3, AUX_CONN4: Conn_01x04_Female; PinHeader_1x04_P2.54mm_Vertical; LCSC C124413
BT1: Battery_Cell; JST_EH_S2B-EH_1x02_P2.50mm_Horizontal; mfr_part_num A2501WR-2P; LCSC C225399
C1, C2: 4.7uF; C_1206_3216Metric; LCSC C412617
C3, C4: 10uF; C_1206_3216Metric; LCSC C92797
C5, C6, C7, C8: 1uF; C_0805_2012Metric; LCSC C28323
C9, C10, C17: 10uF; C_0805_2012Metric; mfr_part_num oops ordered this in 0805; LCSC C40894
C12, C13: 100nF; C_0805_2012Metric; LCSC C495959
C15, C16: 1nF; C_0805_2012Metric; LCSC C309046
D1, D5: D_Schottky; D_SOD-123; LCSC C8598
D2: LED_BLUE; C_0805_2012Metric; LCSC C192320
D3, D4: PWR_LED; LED_0805_2012Metric; LCSC C72037
D6: LED_GREEN; C_0805_2012Metric; LCSC C440522
EXT_BATT1: Conn_01x02_Female; PinHeader_1x02_P2.54mm_Vertical; LCSC C124375
IC1: MiCS-6814; SENSOR_MICS-6814; mfr_part_num MICS-6814; Mouser 523-MICS-6814
J1: USB_B_Micro; USB_Micro-B_Molex-105017-0001; mfr_part_num MicroXNJ; LCSC C404969
J2: PMS7003; mfr_part_num PMS7003; LCSC C84815
L1: 4.7uH; C_0805_2012Metric; LCSC C479902
Q1: SUD08P06-155L; TO-252-2; LCSC C558294
R1, R25: 2k; C_0805_2012Metric; LCSC C328391
R3, R4, R5, R22, R23: 10k; C_0805_2012Metric; LCSC C269724
R6: 330k; C_0805_2012Metric; LCSC C328392
R7, R8: 220k; C_0805_2012Metric; LCSC C294696
R9: 68k; C_0805_2012Metric; LCSC C445663
R10: 820; C_0805_2012Metric; LCSC C352174
R11, R12: 1k5; C_0805_2012Metric; LCSC C203762
R17, R18: 4k7; C_0805_2012Metric; LCSC C269733
R19: 27; C_0805_2012Metric; LCSC C104178
R20: 130; C_0805_2012Metric; LCSC C17451
R24, R26, R28: 470; C_0805_2012Metric; LCSC C136570
R27: 5k1; C_0805_2012Metric; LCSC C328405
SW1, SW2: RESET; SW_SPST_Omron_B3FS-101xP; LCSC C589246
U1: MCP73831-2-OT; SOT-23-5; LCSC C424093
U2: SGM6603-5.0YN6G_TR; SOT-23-6; LCSC C79689
U3: ESP32-WROOM-32; LCSC C82899
U4: SSD1306; SSD1306_OLED-0.91-128x32; mfr_part_num QG-2832TLBFG02; LCSC C91220
U5: BME680; Bosch_LGA-8_3x3mm_P0.8mm_ClockwisePinNumbering; mfr_part_num BME680; LCSC C125972
U6: MH-Z19B; Winsen_MH-Z19B; mfr_part_num MH-Z19B; LCSC C242514
U7: AMS1117-3.3; SOT-223-3_TabPin2; mfr_part_num AMS1117-3.3; LCSC C369933

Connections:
+5V: AUX_CONN2.4, AUX_CONN3.4, C4.1, D1.1 (K), J2.1, J2.2, R10.1, R19.2, R20.2, R25.1, U2.5 (VOUT), U6.6 (Vin), U7.3 (VI)
CO: IC1.H, R7.2, U3.6 (IO34)
EN: R26.2, R27.1, U3.3 (EN)
ESP_RX0: AUX_CONN1.4, U3.34 (RXD0/IO3)
ESP_RX1: AUX_CONN1.2, U3.36 (IO22)
ESP_RX2: J2.7, U3.28 (IO17)
ESP_TX0: AUX_CONN1.3, U3.35 (TXD0/IO1)
ESP_TX1: AUX_CONN1.1, U3.37 (IO23)
ESP_TX2: J2.9, U3.27 (IO16)
GND: 5V_IN1.2, AUX_CONN2.3, AUX_CONN3.3, AUX_CONN4.3, BT1.2 (-), C1.2, C2.2, C3.2, C4.2, C7.2, C8.2, C9.1, C10.1, C12.2, C13.1, C15.1, C16.1, C17.2, D3.1 (K), EXT_BATT1.2, IC1.B, IC1.F, IC1.J, J1.4 (ID), J1.5 (GND), J1.6 (Shield), J2.3, J2.4, R1.2, R4.2, R6.1, R11.1, R12.1, SW1.2, SW2.2, U1.2 (VSS), U2.2 (GND), U3.1 (GND), U3.15 (GND), U3.38 (GND), U3.39 (GND), U4.7 (VSS), U5.1 (GND), U5.5 (SDO), U5.7 (GND), U6.7 (GND), U7.1 (ADJ); also elsewhere on the board
IO0: R24.2, U3.25 (IO0)
LED_BLUE: D2.2 (A), U3.31 (IO19)
LED_GREEN: D6.2 (A), U3.30 (IO18)
NH3: IC1.D, R8.2, U3.8 (IO32)
NO2: IC1.A, R9.2, U3.9 (IO33)
unnamed: 5V_IN1.1, D5.1 (K), J1.1 (VBUS)
unnamed: BT1.1 (+), C2.1, EXT_BATT1.1, Q1.3 (S), U1.3 (VBAT)
unnamed: C1.1, D1.2 (A), D5.2 (A), Q1.1 (G), R4.1, R28.2, U1.4 (VDD)
unnamed: C3.1, L1.1, Q1.2 (D), U2.3 (EN), U2.6 (VCC)
unnamed: C5.1, U4.1 (C2P)
unnamed: C5.2, U4.2 (C2N)
unnamed: C6.1, U4.3 (C1P)
unnamed: C6.2, U4.4 (C1N)
unnamed: C9.2, U4.13 (VCOMH)
unnamed: C10.2, U4.14 (VCC)
unnamed: C15.2, R24.1, SW1.1
unnamed: C16.2, R26.1, SW2.1
unnamed: D2.1 (K), R11.2
unnamed: D3.2 (A), R25.2
unnamed: D4.1 (K), U1.1 (STAT)
unnamed: D4.2 (A), R28.1
unnamed: D6.1 (K), R12.2
unnamed: IC1.C, R19.1
unnamed: IC1.E, IC1.G, R10.2
unnamed: IC1.K, R20.1
unnamed: J1.2 (D-), J1.3 (D+)
unnamed: J2.5, R23.1
unnamed: J2.10, R22.2
unnamed: L1.2, U2.1 (SW)
unnamed: R1.1, U1.5 (PROG)
unnamed: R6.2, U4.12 (IREF)
SCL: AUX_CONN2.2, AUX_CONN3.2, AUX_CONN4.2, R3.2, R18.2, U3.29 (IO5), U4.10 (SCL), U5.4 (SCK)
SDA: AUX_CONN2.1, AUX_CONN3.1, AUX_CONN4.1, R5.2, R17.2, U3.26 (IO4), U4.11 (SDA), U5.3 (SDI)
pwm_mhz19b: U3.33 (IO21), U6.9 (PWM)

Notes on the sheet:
2k resistor = 500mA charge current
Auxillary Breakout Headers
Battery Managment
ESP32
Flashing / Bootmode selection
PMS7003
OLED
5v VCC -> 3v3 VCC
MiCS-6814
address = 0x76
MH-Z19b
BME680

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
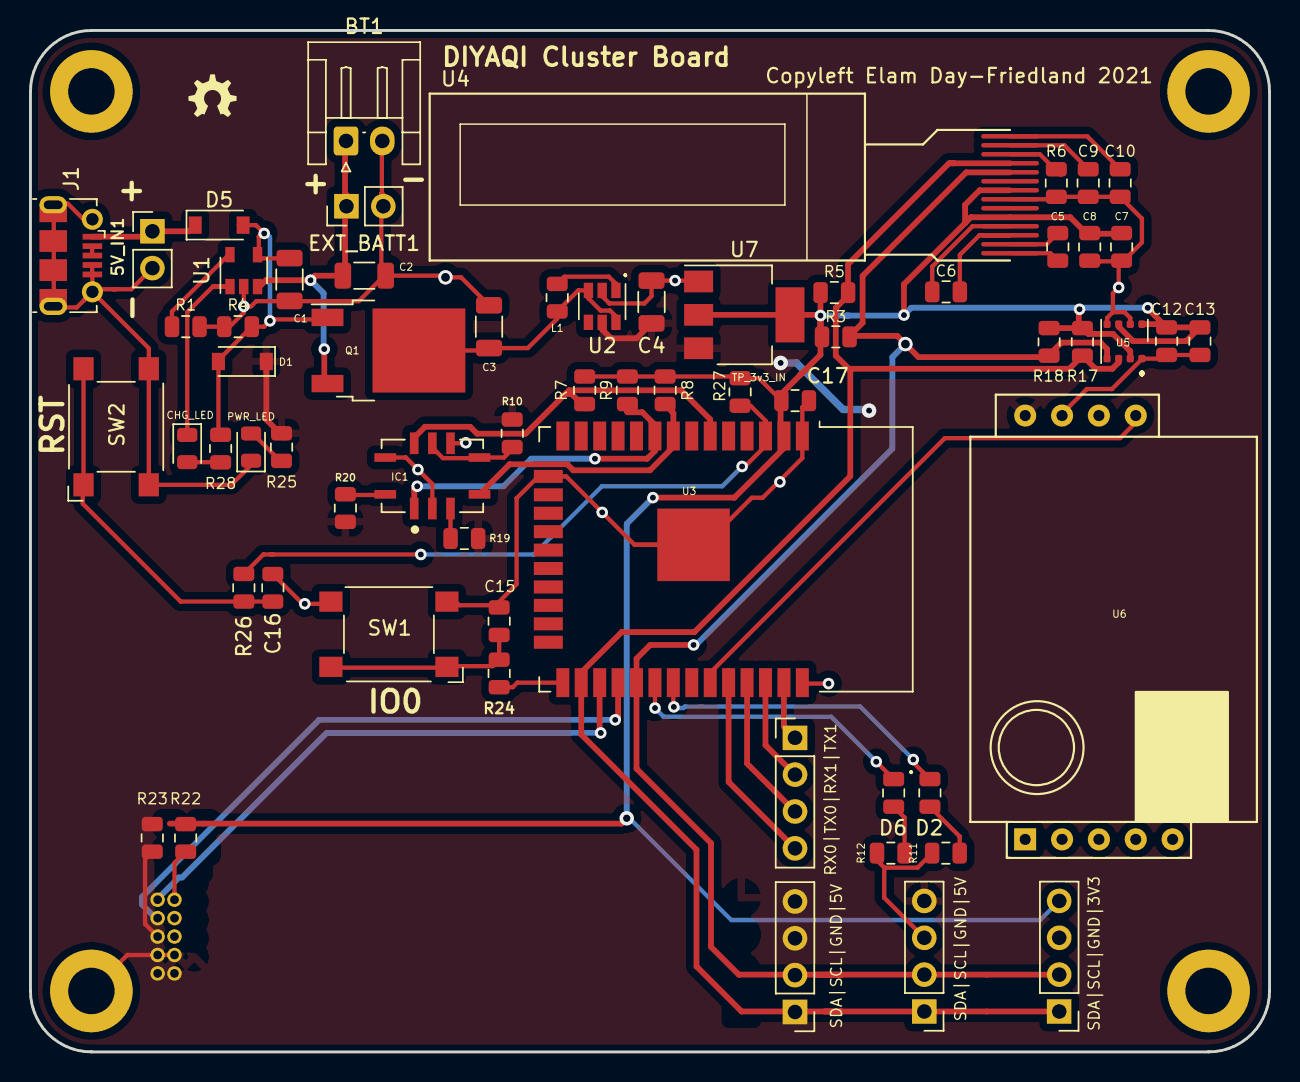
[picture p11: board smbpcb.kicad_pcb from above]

Board: 2 copper layers, 85.4 x 70.4 mm, 65 parts (0 on the bottom side), 45 nets.

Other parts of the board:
MOUNT4: MountingHole_3.2mm_M3_ISO7380_Pad

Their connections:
GND: MOUNT4.1; also elsewhere on the board

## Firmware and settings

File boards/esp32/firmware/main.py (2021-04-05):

"""
This file runs after boot.py on ESP32 boot.
Checks if I can conenct to WLAN from supplied config creds
If I can't, generate setup AP to get creds from user
Once I'm on WLAN, serve sensor configuration over WLAN
"""
import _thread
import time
import usocket as socket
from ap import SetupAp
from setup import SensorConfig
import machine
import cluster
import sys
# TODO use status leds for thigns other than wifi lol (maybe green / red for pollutant levels?)
def sample(clust, lock, interval=30):
    """
    Send periodic measurements from connected sensors, exits when the provided lock is acquired
    """
    # lock is released when user decides to start
    # to be implemented, lol
    while not lock.acquire():
        pass
    lock.release()
    while True:
        print(clust.send_sample())
        time.sleep(interval)
        if lock.locked():
            break


sock = socket.socket(socket.AF_INET, socket.SOCK_STREAM)

setup = SetupAp()

setup.say('bruh')

if not setup.wlan_is_connected():
    # launch setup AP and get valid wifi creds, then reboot
    setup.run(sock)
    setup.say("connected to wifi!")
    time.sleep(1)
    setup.say("rebooting...")
    setup.sta.disconnect()
    machine.reset()

config_lock = _thread.allocate_lock()
sample_lock = _thread.allocate_lock()
config_lock.acquire()
# lock until at least host and sensorname are configured, so we have somewhere to push

setup = SensorConfig(sock,config_lock)
# keeps lock until host and sensorname are entered
#takes and releases lock as config is being read / pages are being sent
_thread.start_new_thread(setup.run, ())

while not config_lock.acquire():
    pass

setup.reset_oled()

# init sensors
sensor_cluster = cluster.Cluster(setup.config)

print('sensor time')
_thread.start_new_thread(sample, (sensor_cluster, sample_lock))

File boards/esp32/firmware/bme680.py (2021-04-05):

# Spaces, comments and some functions have been removed from the original file to save memory
# Original source: https://github.com/adafruit/Adafruit_CircuitPython_BME680/blob/master/adafruit_bme680.py
import time
import math
from micropython import const
from ubinascii import hexlify as hex
try:
  import struct
except ImportError:
  import ustruct as struct
_BME680_CHIPID = const(0x61)
_BME680_REG_CHIPID = const(0xD0)
_BME680_BME680_COEFF_ADDR1 = const(0x89)
_BME680_BME680_COEFF_ADDR2 = const(0xE1)
_BME680_BME680_RES_HEAT_0 = const(0x5A)
_BME680_BME680_GAS_WAIT_0 = const(0x64)
_BME680_REG_SOFTRESET = const(0xE0)
_BME680_REG_CTRL_GAS = const(0x71)
_BME680_REG_CTRL_HUM = const(0x72)
_BME280_REG_STATUS = const(0xF3)
_BME680_REG_CTRL_MEAS = const(0x74)
_BME680_REG_CONFIG = const(0x75)
_BME680_REG_PAGE_SELECT = const(0x73)
_BME680_REG_MEAS_STATUS = const(0x1D)
_BME680_REG_PDATA = const(0x1F)
_BME680_REG_TDATA = const(0x22)
_BME680_REG_HDATA = const(0x25)
_BME680_SAMPLERATES = (0, 1, 2, 4, 8, 16)
_BME680_FILTERSIZES = (0, 1, 3, 7, 15, 31, 63, 127)
_BME680_RUNGAS = const(0x10)
_LOOKUP_TABLE_1 = (2147483647.0, 2147483647.0, 2147483647.0, 2147483647.0, 2147483647.0,
  2126008810.0, 2147483647.0, 2130303777.0, 2147483647.0, 2147483647.0,
  2143188679.0, 2136746228.0, 2147483647.0, 2126008810.0, 2147483647.0,
  2147483647.0)
_LOOKUP_TABLE_2 = (4096000000.0, 2048000000.0, 1024000000.0, 512000000.0, 255744255.0, 127110228.0,
  64000000.0, 32258064.0, 16016016.0, 8000000.0, 4000000.0, 2000000.0, 1000000.0,
  500000.0, 250000.0, 125000.0)
def _read24(arr):
  ret = 0.0
  for b in arr:
    ret *= 256.0
    ret += float(b & 0xFF)
  return ret
class Adafruit_BME680:
  def __init__(self, *, refresh_rate=10):
    self._write(_BME680_REG_SOFTRESET, [0xB6])
    time.sleep(0.005)
    chip_id = self._read_byte(_BME680_REG_CHIPID)
    if chip_id != _BME680_CHIPID:
      raise RuntimeError('Failed 0x%x' % chip_id)
    self._read_calibration()
    self._write(_BME680_BME680_RES_HEAT_0, [0x73])
    self._write(_BME680_BME680_GAS_WAIT_0, [0x65])
    self.sea_level_pressure = 1013.25
    self._pressure_oversample = 0b011
    self._temp_oversample = 0b100
    self._humidity_oversample = 0b010
    self._filter = 0b010
    self._adc_pres = None
    self._adc_temp = None
    self._adc_hum = None
    self._adc_gas = None
    self._gas_range = None
    self._t_fine = None
    self._last_reading = 0
    self._min_refresh_time = 1000 / refresh_rate
  @property
  def pressure_oversample(self):
    return _BME680_SAMPLERATES[self._pressure_oversample]
  @pressure_oversample.setter
  def pressure_oversample(self, sample_rate):
    if sample_rate in _BME680_SAMPLERATES:
      self._pressure_oversample = _BME680_SAMPLERATES.index(sample_rate)
    else:
      raise RuntimeError("Invalid")
  @property
  def humidity_oversample(self):
    return _BME680_SAMPLERATES[self._humidity_oversample]
  @humidity_oversample.setter
  def humidity_oversample(self, sample_rate):
    if sample_rate in _BME680_SAMPLERATES:
      self._humidity_oversample = _BME680_SAMPLERATES.index(sample_rate)
    else:
      raise RuntimeError("Invalid")
  @property
  def temperature_oversample(self):
      return _BME680_SAMPLERATES[self._temp_oversample]
  @temperature_oversample.setter
  def temperature_oversample(self, sample_rate):
    if sample_rate in _BME680_SAMPLERATES:
      self._temp_oversample = _BME680_SAMPLERATES.index(sample_rate)
    else:
      raise RuntimeError("Invalid")
  @property
  def filter_size(self):
    return _BME680_FILTERSIZES[self._filter]
  @filter_size.setter
  def filter_size(self, size):
    if size in _BME680_FILTERSIZES:
      self._filter = _BME680_FILTERSIZES[size]
    else:
      raise RuntimeError("Invalid")
  @property
  def temperature(self):
    self._perform_reading()
    calc_temp = (((self._t_fine * 5) + 128) / 256)
    return calc_temp / 100
  @property
  def pressure(self):
    self._perform_reading()
    var1 = (self._t_fine / 2) - 64000
    var2 = ((var1 / 4) * (var1 / 4)) / 2048
    var2 = (var2 * self._pressure_calibration[5]) / 4
    var2 = var2 + (var1 * self._pressure_calibration[4] * 2)
    var2 = (var2 / 4) + (self._pressure_calibration[3] * 65536)
    var1 = (((((var1 / 4) * (var1 / 4)) / 8192) *
      (self._pressure_calibration[2] * 32) / 8) +
      ((self._pressure_calibration[1] * var1) / 2))
    var1 = var1 / 262144
    var1 = ((32768 + var1) * self._pressure_calibration[0]) / 32768
    calc_pres = 1048576 - self._adc_pres
    calc_pres = (calc_pres - (var2 / 4096)) * 3125
    calc_pres = (calc_pres / var1) * 2
    var1 = (self._pressure_calibration[8] * (((calc_pres / 8) * (calc_pres / 8)) / 8192)) / 4096
    var2 = ((calc_pres / 4) * self._pressure_calibration[7]) / 8192
    var3 = (((calc_pres / 256) ** 3) * self._pressure_calibration[9]) / 131072
    calc_pres += ((var1 + var2 + var3 + (self._pressure_calibration[6] * 128)) / 16)
    return calc_pres/100
  @property
  def humidity(self):
    self._perform_reading()
    temp_scaled = ((self._t_fine * 5) + 128) / 256
    var1 = ((self._adc_hum - (self._humidity_calibration[0] * 16)) -
      ((temp_scaled * self._humidity_calibration[2]) / 200))
    var2 = (self._humidity_calibration[1] *
      (((temp_scaled * self._humidity_calibration[3]) / 100) +
       (((temp_scaled * ((temp_scaled * self._humidity_calibration[4]) / 100)) /
         64) / 100) + 16384)) / 1024
    var3 = var1 * var2
    var4 = self._humidity_calibration[5] * 128
    var4 = (var4 + ((temp_scaled * self._humidity_calibration[6]) / 100)) / 16
    var5 = ((var3 / 16384) * (var3 / 16384)) / 1024
    var6 = (var4 * var5) / 2
    calc_hum = (((var3 + var6) / 1024) * 1000) / 4096
    calc_hum /= 1000
    if calc_hum > 100:
      calc_hum = 100
    if calc_hum < 0:
      calc_hum = 0
    return calc_hum
  @property
  def altitude(self):
    pressure = self.pressure
    return 44330 * (1.0 - math.pow(pressure / self.sea_level_pressure, 0.1903))
  @property
  def gas(self):
    self._perform_reading()
    var1 = ((1340 + (5 * self._sw_err)) * (_LOOKUP_TABLE_1[self._gas_range])) / 65536
    var2 = ((self._adc_gas * 32768) - 16777216) + var1
    var3 = (_LOOKUP_TABLE_2[self._gas_range] * var1) / 512
    calc_gas_res = (var3 + (var2 / 2)) / var2
    return int(calc_gas_res)
  def _perform_reading(self):
    if (time.ticks_diff(self._last_reading, time.ticks_ms()) * time.ticks_diff(0, 1)
        < self._min_refresh_time):
      return
    self._write(_BME680_REG_CONFIG, [self._filter << 2])
    self._write(_BME680_REG_CTRL_MEAS,
      [(self._temp_oversample << 5)|(self._pressure_oversample << 2)])
    self._write(_BME680_REG_CTRL_HUM, [self._humidity_oversample])
    self._write(_BME680_REG_CTRL_GAS, [_BME680_RUNGAS])
    ctrl = self._read_byte(_BME680_REG_CTRL_MEAS)
    ctrl = (ctrl & 0xFC) | 0x01
    self._write(_BME680_REG_CTRL_MEAS, [ctrl])
    new_data = False
    while not new_data:
      data = self._read(_BME680_REG_MEAS_STATUS, 15)
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

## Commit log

2021-01-20 now parses multiple sensors from config
2021-01-20 multi sensor POSTing baby
2021-01-20 forgot to update sensor message
2021-01-21 added schematics
2021-01-21 everything is probably broken now... WIP
    [read_pwm.py, test_bme280.py, test_cjmcu_ads1115.py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]
2021-01-23 slightly less broken probably make it read from a config file
    [main.py]
2021-01-29 working pcb
2021-01-29 pls do recheck sensors on boot
2021-01-29 fixed config read error
    [postaqi.py]
2021-01-30 begining of sensor detection
2021-02-09 smt time
    [smbpcb.kicad_pcb, smbpcb.kicad_sch]
2021-02-09 pms7003 time
    [smbpcb.kicad_pcb, smbpcb.kicad_sch]
2021-02-09 more work'
    [smbpcb.kicad_pcb, smbpcb.kicad_sch]
2021-02-10 ordering dis
    [bom.csv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]
2021-02-14 updated bom w mfr part nums
    [bom.csv]
2021-02-14 added decoupling cap to 3v3 off of esp32 board
    [smbpcb.kicad_pcb, smbpcb.kicad_sch]
2021-02-15 ohl for the pcb stuff
2021-02-16 added mouser part nums"
    [bom.csv]
2021-02-16 updated bom
    [smbpcb.kicad_sch]
2021-02-20 box time
    [enclosure.FCStd]
2021-02-20 lid and rearranging
    [30mm_fan_guard.FCStd, 30mm_fan_guard.stl, enclosure.FCStd]
2021-02-20 made everything 0805 or bigger except that nagging BGA Linear regulator and the bme680
    [bom.csv, smbpcb.kicad_pcb, smbpcb.kicad_sch]
2021-02-21 made more parametric and added battery part
    [2000mAh Battery.step, enclosure-bodyv1.0.0.stl, enclosure-lidv1.0.0.stl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]
2021-02-21 fan time
    [30mm_fan_guard.FCStd, 30mm_fan_guard.stl, 30mmfan.step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]
2021-02-21 vent holes
    [enclosure.FCStd]
2021-02-22 tidied up
    [smbpcb.kicad_pcb]
2021-02-22 more tidying and controled impedence traces for important stuff
    [smbpcb.kicad_pcb]
2021-02-22 assembly QOL improvements
    [smbpcb.kicad_pcb, smbpcb.kicad_sch]
2021-02-22 added dot for bme680
    [smbpcb.kicad_pcb]
2021-02-22 these probbaly should have been 1 commit
    [smbpcb.kicad_pcb]
2021-02-24 wrong micro usb footprint
    [smbpcb.kicad_pcb, smbpcb.kicad_sch]
2021-02-24 forgot to save
    [smbpcb.kicad_sch]
2021-02-25 v1 probably
    [bom.csv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]
2021-02-25 added silkscreen stuff
    [smbpcb-B_Cu.gbr, smbpcb-B_Mask.gbr, smbpcb-B_Paste.gbr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]
2021-03-01 printing these full scale
    [enclosure-bodyv1.0.0.stl, enclosure-lidv1.0.0.stl]
2021-03-04 finally got the actual board in gonna use idf and just deploy firmwares cuz idk why but ampy and others don't work
    [enclosure.FCStd]
2021-03-04 fixed tolerences for fan
    [enclosure.FCStd]
2021-03-05 sensor reg kinda wokrs
2021-03-07 sensor time
2021-03-08 switch footprints were wrong..."
    [smbpcb.kicad_pcb, smbpcb.kicad_sch]
2021-03-08 swapped header order to be more standard
    [smbpcb.kicad_pcb, smbpcb.kicad_sch]
2021-03-08 pulled up io0 instaed of en. dhmu
    [smbpcb.kicad_sch]
2021-03-08 turns out mhz19b uses 3v3 logic and also uart doesn't work
    [smbpcb.kicad_pcb, smbpcb.kicad_sch]
2021-03-10 mics still broken, sensors otherwise good
    [ap.py, mics6814.py, webtool.py]
2021-03-12 mics sucks lol
    [smbpcb.kicad_pcb, smbpcb.kicad_sch]
2021-03-13 woot woot all 4 sensors work! (bme280)
2021-03-14 fixed mics pullups
    [smbpcb.kicad_pcb, smbpcb.kicad_sch]
2021-03-16 moving stuff
    [2000mAh Battery.step, 30mmfan.step, bom.csv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]
2021-03-16 added status leds
    [smbpcb.kicad_pcb, smbpcb.kicad_sch]
2021-03-16 led time
    [bom.csv]
2021-03-20 adding stls too incase you don't want to download freecad
    [enclosure-lid.stl, enclosure-rain_cover.stl]
2021-03-20 changed some title block stuff
    [smbpcb.kicad_pcb, smbpcb.kicad_sch]
2021-03-20 better schematic
2021-03-20 enclosure prettificaiton
    [enclosure.FCStd]
2021-03-20 more readable schematic
    [smbpcb.kicad_sch]
2021-03-21 gerbers n stuff
    [smbpcb-B_Cu.gbr, smbpcb-B_Mask.gbr, smbpcb-B_Paste.gbr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]
2021-03-21 went through DRC
    [smbpcb-B_Cu.gbr, smbpcb-B_Mask.gbr, smbpcb-B_Paste.gbr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]
2021-03-21 in case you're SUPER lazyu
2021-03-21 moved bom
    [bom.csv]
2021-03-21 added bom to src zip
    [bom.csv]
2021-04-01 removed oled reset pullup it broke the oled
    [smbpcb-B_Cu.gbr, smbpcb-B_Mask.gbr, smbpcb-B_Paste.gbr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]
2021-04-01 more minor stuff
    [smbpcb.kicad_pcb]
2021-04-04 status leds! sequence is in for wifi at least using threads

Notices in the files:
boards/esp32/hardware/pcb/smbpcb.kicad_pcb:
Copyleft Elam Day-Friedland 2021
